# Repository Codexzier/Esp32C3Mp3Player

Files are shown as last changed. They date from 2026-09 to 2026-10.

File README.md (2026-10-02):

# Esp32C3Mp3Player
 A simple MP3 Player with ESP32-C3.

Einfacher MP3 Player auf Basis eines **ESP32-C3 Dev Moduls** (Variante mit I²C auf
GPIO8 = SDA und GPIO9 = SCL, z.B. ESP32-C3 SuperMini). Die MP3s liegen nach Kategorien
sortiert in Ordnern auf einer SD Karte und werden über einen PCM5102 I2S DAC ausgegeben.

## Benötigte Bauteile

| Bauteil | Hinweis |
|---|---|
| ESP32-C3 Dev Modul | Variante SDA = GPIO8, SCL = GPIO9 |
| OLED Display 128x32 | SSD1306, I²C, Adresse 0x3C |
| SD Karten Leser | SPI, FAT32 formatierte SD Karte |
| PCM5102 I2S DAC Modul | "PCM5102 I2S IIS Lossless Digital Audio DAC Decoder" |
| 2 Taster | Schließer, gegen GND |
| Potentiometer 10 kΩ | linear, für die Lautstärke |
| 2 Widerstände 100 kΩ | Spannungsteiler für die Akku Messung |
| LiPo / Li-Ion Akku (1 Zelle) | mit Lade-/Schutzschaltung (z.B. TP4056) |

## Pin Belegung

| GPIO | Funktion | Anschluss am Modul |
|---|---|---|
| GPIO0 | ADC – Lautstärke | Potentiometer Schleifer (Mitte) |
| GPIO1 | ADC – Akku Messung | Mitte Spannungsteiler 100k/100k |
| GPIO2 | I2S Daten | PCM5102 **DIN** |
| GPIO3 | Taster 1 (Play / nächster Titel) | Taster gegen GND |
| GPIO4 | SPI SCK | SD Karte **SCK** |
| GPIO5 | SPI MISO | SD Karte **MISO** |
| GPIO6 | SPI MOSI | SD Karte **MOSI** |
| GPIO7 | SPI CS | SD Karte **CS** |
| GPIO8 | I²C SDA | OLED **SDA** |
| GPIO9 | I²C SCL | OLED **SCL** |
| GPIO10 | I2S Bit Clock | PCM5102 **BCK** |
| GPIO20 | Taster 2 (Stop / nächste Kategorie) | Taster gegen GND |
| GPIO21 | I2S Word Select | PCM5102 **LCK** |

### OLED Display 128x32

| OLED | ESP32-C3 |
|---|---|
| VCC | 3V3 |
| GND | GND |
| SDA | GPIO8 |
| SCL | GPIO9 |

### SD Karten Leser

| SD Modul | ESP32-C3 |
|---|---|
| VCC | 3V3 (bzw. 5V, wenn das Modul einen eigenen Spannungsregler hat) |
| GND | GND |
| SCK | GPIO4 |
| MISO | GPIO5 |
| MOSI | GPIO6 |
| CS | GPIO7 |

### PCM5102 I2S DAC

| PCM5102 | ESP32-C3 / Anschluss |
|---|---|
| VIN | 3V3 (oder 5V) |
| GND | GND |
| BCK | GPIO10 |
| DIN | GPIO2 |
| LCK | GPIO21 |
| SCK | **GND** (der DAC erzeugt den Systemtakt dann selbst) |
| FLT | GND (normaler Filter) |
| DEMP | GND (De-Emphasis aus) |
| XSMT | **3V3** (Soft-Mute aus, sonst bleibt der Ausgang stumm) |
| FMT | GND (I2S Format) |

Bei vielen PCM5102 Modulen sind FLT, DEMP, XSMT und FMT über Lötbrücken (H/L) auf der
Rückseite eingestellt und SCK ist schon mit GND verbunden – dann müssen diese Pins nicht
extra verdrahtet werden. Der Kopfhörer bzw. Verstärker kommt an den Line-Out (3,5 mm Klinke
oder L / G / R).

### Taster

Beide Taster schalten den GPIO gegen GND. Es werden die internen Pull-Up Widerstände
verwendet, externe Widerstände sind nicht nötig.

| Taster | ESP32-C3 | Funktion |
|---|---|---|
| Taster 1 | GPIO3 ↔ GND | Play, bei erneutem Drücken nächster Titel |
| Taster 2 | GPIO20 ↔ GND | Titel anhalten und zur nächsten Kategorie wechseln |

### Potentiometer (Lautstärke)

| Potentiometer | ESP32-C3 |
|---|---|
| Äußerer Pin 1 | GND |
| Schleifer (Mitte) | GPIO0 |
| Äußerer Pin 2 | 3V3 |

### Akku Messung

Der Akku wird über einen Spannungsteiler (2 × 100 kΩ) gemessen, damit am ADC maximal
ca. 2,1 V anliegen:

```
Akku + ──[100k]──┬──[100k]── GND
                 │
               GPIO1
```

Wird keine Akkuspannung erkannt (Betrieb nur über USB), zeigt die Akku Anzeige nur den
Rahmen und es findet keine Abschaltung statt.

### Hinweise zu den Pins

- GPIO20/21 sind beim ESP32-C3 die Pins der UART0 (RX/TX). Da sie hier für Taster 2 und
  den DAC verwendet werden, in der Arduino IDE **"USB CDC On Boot: Enabled"** einstellen,
  damit die serielle Konsole über den nativen USB Anschluss läuft.
- GPIO2, GPIO8 und GPIO9 sind Strapping Pins. Sie werden hier nur als Ausgang (DIN) bzw.
  für I²C genutzt, die Taster liegen bewusst nicht auf diesen Pins.

## Platine (PCB)

Im Ordner [`hardware/`](hardware/) liegt ein KiCad-Projekt (Schaltplan und geroutete Platine,
88 × 52 mm, 2 Lagen). Die Module werden auf beiden Seiten der Platine gesteckt: SuperMini,
OLED, Taster, Poti und Ein/Aus-Schalter auf der Oberseite, SD-Modul, PCM5102, HW-104
(PAM8403) und TP4056 auf der Unterseite. Die Pinbelegung ist dieselbe wie oben. Zusätzlich
sind der Akku-Pfad mit Lademodul, Schalter und Schottky-Diode sowie Kondensatoren gegen
Störgeräusche am Verstärker vorgesehen.

Einige Modulmaße sind geschätzt – vor der Bestellung bitte die Hinweise in der
[Platinen-README](hardware/README.md) beachten.

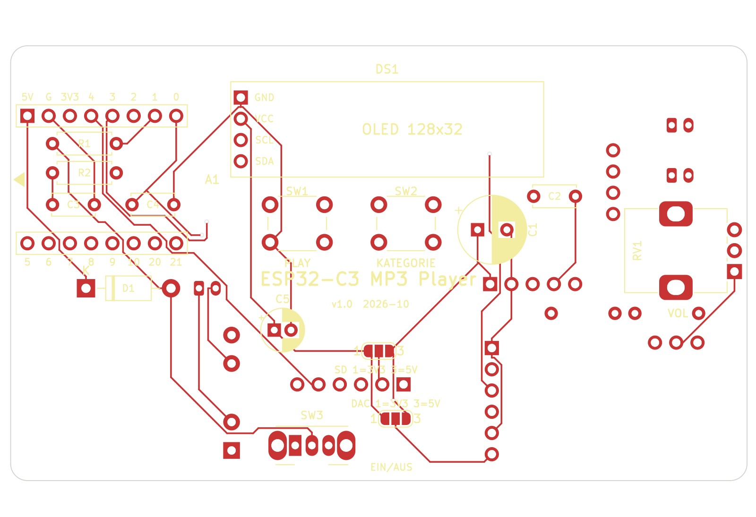
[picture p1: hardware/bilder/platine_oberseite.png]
Platine Oberseite


## SD Karte

Die SD Karte muss FAT32 formatiert sein. Jeder Ordner im Hauptverzeichnis ist eine
Kategorie, die MP3s liegen direkt in diesen Ordnern:

```
/Chillout/Titel 1.mp3
/Dokumentation/...
/Lofi/...
/Work/...
```

Werden auf der SD Karte keine Ordner gefunden, legt der Player die Ordner **Chillout**,
**Work**, **Dokumentation** und **Lofi** an und zeigt den Hinweis, dass noch keine MP3s
gespeichert sind. Standard Kategorie beim Einschalten ist *Chillout*.

## Bedienung / Anzeige

1. **Einschalten:** Schiebetüren Animation, danach der Start Text
   - Zeile 1: `ESP32 MP3 Player`
   - Zeile 2: `Press Play (Anzahl Titel)`
   - Zeile 3: `Kat: <Ordner>`
2. **Taster 1:** Wiedergabe startet
   - Zeile 1: Titel der MP3 (lange Titel laufen als Lauftext durch)
   - Zeile 2: `Anzahl Titel: <Anzahl>`
   - Erneutes Drücken spielt den nächsten Titel, nach dem letzten Titel geht es wieder
     beim ersten los. Ist ein Titel zu Ende, wird automatisch der nächste gespielt.
3. **Taster 2:** Wiedergabe wird angehalten und die nächste Kategorie (Ordner) gewählt.
   Es wird wieder der Start Text mit der neuen Kategorie angezeigt.
4. **Potentiometer:** Lautstärke, angezeigt als 2 Pixel hoher Balken in den unteren beiden
   Pixelzeilen (31 und 32).
5. **Akku:** Wird alle 30 Sekunden und bei jedem Titelwechsel gemessen und rechts als
   Balken angezeigt. Bei 1 % wird die Wiedergabe gestoppt und angezeigt:
   - Zeile 1: `Batteriestand: 1%`
   - Zeile 2: `Bitte Aufladen`
   - Zeile 3: `Abschaltung in 30s` (zählt herunter)

   Bei 0 Sekunden wird das Display abgeschaltet und der ESP32 geht in den Deep Sleep.
   Neustart über Reset bzw. Aus- und wieder Einschalten.

## Software

Arduino IDE mit dem **esp32** Board Paket von Espressif (Version 3.x), Board
**"ESP32C3 Dev Module"**, *USB CDC On Boot: Enabled*.

Benötigte Bibliotheken:

- Adafruit GFX Library
- Adafruit SSD1306
- [arduino-audio-tools](https://github.com/pschatzmann/arduino-audio-tools)
- [arduino-libhelix](https://github.com/pschatzmann/arduino-libhelix) (MP3 Decoder)

Die beiden Audio Bibliotheken sind nicht im Bibliotheksverwalter enthalten und werden als
ZIP von GitHub heruntergeladen und über *Sketch → Bibliothek einbinden → .ZIP-Bibliothek
hinzufügen* installiert.

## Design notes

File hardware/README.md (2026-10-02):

# Platine ESP32-C3 MP3 Player

KiCad-Projekt für eine doppelseitig bestückte Platine (88 × 52 mm, 2 Lagen). Alle Module
sitzen auf der Platine. Der ESP32-C3 SuperMini wird auf Buchsenleisten gesteckt.

> **Wichtig:** Die Maße und Pin-Positionen einiger Module sind geschätzt (siehe
> [Vor der Bestellung prüfen](#vor-der-bestellung-prüfen)). Bitte die Footprints mit den
> eigenen Modulen vergleichen und bei Bedarf in KiCad anpassen, bevor die Platine bestellt wird.

| Oberseite (Bedienseite) | Unterseite (von unten gesehen) |
|---|---|
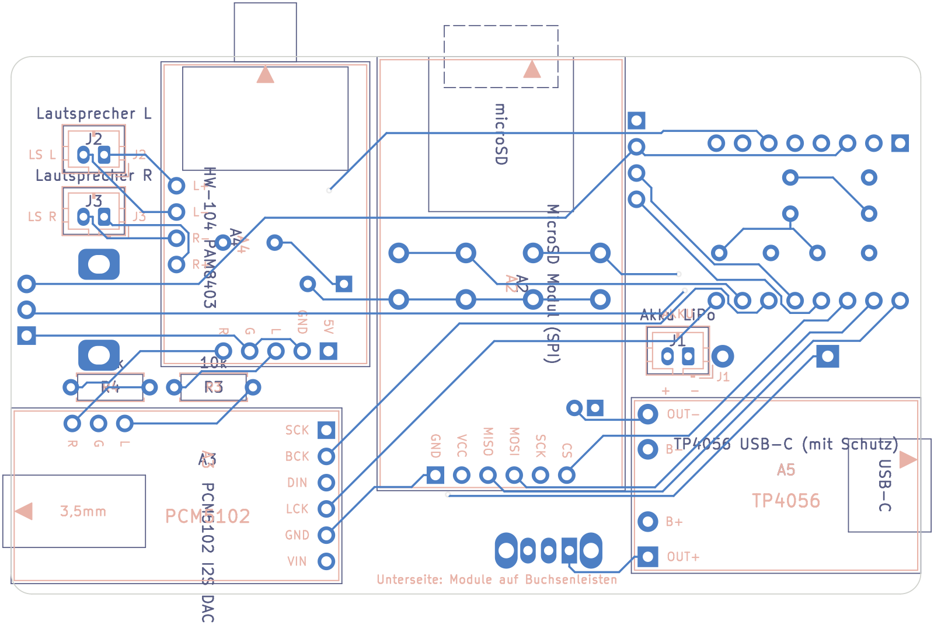
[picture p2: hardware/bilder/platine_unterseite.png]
Unterseite
| Oberseite |  |

Schaltplan: [Esp32C3Mp3Player-Schaltplan.pdf](Esp32C3Mp3Player-Schaltplan.pdf) bzw.
[bilder/schaltplan.png](bilder/schaltplan.png)

## Dateien

| Datei | Inhalt |
|---|---|
| `Esp32C3Mp3Player.kicad_pro` | KiCad-Projekt (Netzklassen: Signale 0,3 mm, Versorgung 0,6 mm) |
| `Esp32C3Mp3Player.kicad_sch` | Schaltplan |
| `Esp32C3Mp3Player.kicad_pcb` | Platine (geroutet, GND-Flächen auf beiden Lagen) |
| `Esp32C3Mp3Player.kicad_sym` | Symbole der Module |
| `Esp32C3Mp3Player.pretty/` | Footprints der Module |
| `fp-lib-table`, `sym-lib-table` | binden die beiden Projekt-Bibliotheken ein |

Erstellt mit KiCad 7.0. Die Dateien lassen sich mit KiCad 8 und 9 öffnen, beim Speichern werden
sie in das neue Format umgewandelt. Standardbauteile (Widerstände, Taster, ...) stammen aus den
KiCad-Standardbibliotheken.

## Aufbau

### Oberseite (Bedienseite)

| Ref | Bauteil | Lage |
|---|---|---|
| A1 | ESP32-C3 SuperMini auf 2 × Buchsenleiste 1×8 | links, USB-C an der linken Kante |
| DS1 | OLED 0,91" 128×32 | oben Mitte |
| SW1, SW2 | Taster 6×6 mm (Play/Next, Kategorie) | unter dem Display |
| RV1 | Poti 10k linear (9 mm, Alps RK09K o.ä.) | rechts |
| SW3 | Schiebeschalter Ein/Aus (C&K OS102011MA1Q, 2 mm Raster) | untere Kante, Hebel zeigt nach außen |
| R1, R2, C3, C4 | Spannungsteiler Akku, Filter-Kondensatoren | unter dem SuperMini |
| D1, C1, C2, C5 | Schottky-Diode, Elkos, 100 nF | freie Flächen |
| JP1, JP2 | Lötbrücken für die Versorgung von SD-Modul und DAC | Mitte unten |

### Unterseite

| Ref | Bauteil | Lage |
|---|---|---|
| A2 | MicroSD-Modul (SPI, 42 × 24 mm) | Mitte, Kartenschlitz an der oberen Kante |
| A3 | PCM5102 DAC | rechts unten, 3,5-mm-Klinke an der rechten Kante |
| A4 | HW-104 (PAM8403) | rechts oben, Poti-Achse an der oberen Kante |
| A5 | TP4056 USB-C Lademodul | links unten, USB-C an der linken Kante |
| J1 | Akku (JST-PH 2 mm) | links |
| J2, J3 | Lautsprecher links/rechts (JST-PH 2 mm) | rechts oben |
| R3, R4 | 10 k Vorwiderstände Audio | zwischen DAC und Verstärker |

Die Module auf der Unterseite werden ebenfalls auf **Buchsenleisten** gesteckt (8,5 mm hoch).
Dadurch ist genug Abstand zu den Lötstellen der Bauteile auf der Oberseite. Nur der **TP4056**
wird mit kurzen Stiftleisten-Pins direkt angelötet; unter ihm liegen deshalb keine Lötstellen.

## Schaltung

Die Pinbelegung des ESP32-C3 ist dieselbe wie in der [README](../README.md) und im Sketch:

| GPIO | Signal | GPIO | Signal |
|---|---|---|---|
| GPIO0 | Poti (Lautstärke) | GPIO6 | SD MOSI |
| GPIO1 | Akku-Messung | GPIO7 | SD CS |
| GPIO2 | I2S DIN → PCM5102 | GPIO8 | I²C SDA (OLED) |
| GPIO3 | Taster Play/Next | GPIO9 | I²C SCL (OLED) |
| GPIO4 | SD SCK | GPIO10 | I2S BCK → PCM5102 |
| GPIO5 | SD MISO | GPIO20 | Taster Kategorie |
| | | GPIO21 | I2S LCK → PCM5102 |

**Stromversorgung:** Akku (J1) → TP4056 (B+/B−) → OUT+ → Schalter SW3 → Schottky-Diode D1 →
5V-Pin des SuperMini. Geladen wird über die USB-C-Buchse des TP4056. Steckt USB am SuperMini,
läuft der Player über USB; D1 verhindert, dass dabei 5 V in den Akku zurückfließen. R1/R2 teilen
die Akkuspannung (hinter dem Schalter) für GPIO1. Ist der Schalter aus, misst die Firmware keinen
Akku und schaltet nicht ab.

**Audio:** PCM5102 L/R → R3/R4 (10 k) → Eingang HW-104 → Lautsprecher an J2/J3 (Brückenausgang:
L+/L− bzw. R+/R−, **nicht** mit GND verbinden). C1 (470 µF) und C2 (100 nF) sitzen direkt an der
Versorgung des Verstärkers, beide Lagen sind GND-Flächen. Das hilft gegen das Störgeräusch.
Ist es zu leise, R3/R4 durch Drahtbrücken ersetzen. SCK des PCM5102 liegt auf GND (interner Takt).

### Lötbrücken JP1 und JP2 (müssen geschlossen werden!)

Ohne Brücke bekommen SD-Modul bzw. DAC keinen Strom. Die mittlere Fläche (2) wird mit einer der
äußeren verbunden:

| Brücke | 1–2 (3,3 V) | 2–3 (5 V) |
|---|---|---|
| JP1 (SD-Modul) | SD-Modul ohne eigenen Spannungsregler | Catalex-Modul mit AMS1117-Regler |
| JP2 (PCM5102) | empfohlen | möglich (Modul hat eigene Regler) |

Hinweis zum Akkubetrieb: Am 5V-Pin liegen dann nur etwa 3,0 – 3,9 V (Akku minus Diode). Ein
SD-Modul mit AMS1117-Regler bekommt daran zu wenig Spannung. Für Akkubetrieb ein SD-Modul ohne
Regler an 3,3 V nehmen (JP1 auf 1–2).

## Stückliste

| Ref | Wert | Bauform / Footprint | Menge |
|---|---|---|---|
| A1 | ESP32-C3 SuperMini | + 2 × Buchsenleiste 1×8, 2,54 mm | 1 |
| DS1 | OLED 0,91" 128×32 I²C | + Buchsenleiste 1×4 | 1 |
| A2 | MicroSD-Modul SPI | + Buchsenleiste 1×6 | 1 |
| A3 | PCM5102 DAC | + Buchsenleisten 1×6 und 1×3 | 1 |
| A4 | HW-104 PAM8403 | + Buchsenleisten 1×5 und 1×4 | 1 |
| A5 | TP4056 USB-C mit Schutzschaltung | 4 einzelne Stiftleisten-Pins | 1 |
| SW1, SW2 | Taster | 6 × 6 mm THT | 2 |
| SW3 | Schiebeschalter 1×UM | C&K OS102011MA1Q (2 mm Raster, gewinkelt) | 1 |
| RV1 | 10 k linear | Alps RK09K stehend (9 mm) | 1 |
| R1, R2 | 100 k | 0207, Raster 7,62 mm | 2 |
| R3, R4 | 10 k | 0207, Raster 7,62 mm | 2 |
| C1 | 470 µF / 10 V | Elko radial 8 mm, Raster 3,5 mm | 1 |
| C5 | 100 µF / 10 V | Elko radial 5 mm, Raster 2 mm | 1 |
| C2, C3, C4 | 100 nF | Keramik, Raster 5 mm | 3 |
| D1 | 1N5817 | DO-41 | 1 |
| J1, J2, J3 | JST-PH 2-polig | B2B-PH-K, stehend | 3 |
| H1–H4 | Befestigungsloch M3 | | 4 |

## Bestückung

1. Lötbrücken JP1 und JP2 setzen (siehe oben).
2. Flache Bauteile auf der Oberseite: R1, R2, C3, C4 (unter dem SuperMini), D1, C2, C5.
3. Taster, Poti, Schiebeschalter, C1.
4. Buchsenleisten für SuperMini und OLED auf der Oberseite.
5. Unterseite: R3, R4, J1–J3, dann die Buchsenleisten für SD-Modul, PCM5102 und HW-104.
6. TP4056 mit kurzen Pins auf der Unterseite anlöten.
7. Module aufstecken.

Die Lötstellen der Buchsenleisten liegen jeweils auf der Gegenseite. Deshalb die Buchsenleisten
löten, bevor die Module aufgesteckt werden.

## Vor der Bestellung prüfen

Einige Datenblätter waren nicht erreichbar. Diese Angaben sind deshalb geschätzt:

| Modul | Annahme | Was prüfen |
|---|---|---|
| ESP32-C3 SuperMini | 22,52 × 18 mm, Reihenabstand 15,24 mm, Pin 1 (5V) 2 mm von der USB-Kante. Von oben, USB links: obere Reihe 5V, GND, 3V3, 4, 3, 2, 1, 0; untere Reihe 5, 6, 7, 8, 9, 10, 20, 21 | Reihenfolge der Pinreihen. Sind die Reihen vertauscht, lässt sich der SuperMini mit der Bauteilseite nach unten aufstecken (USB bleibt links). Besser: Footprint anpassen |
| OLED 0,91" | 38 × 12 mm, Pins GND, VCC, SCL, SDA | Bei manchen Modulen sind VCC und GND vertauscht! |
| MicroSD-Modul | 42 × 24 mm (Catalex-Bauform), Pins GND, VCC, MISO, MOSI, SCK, CS, 4 Löcher M2 | Pinreihenfolge und Lage der Befestigungslöcher |
| PCM5102 | 17 × 32 mm, Leiste SCK, BCK, DIN, LCK, GND, VIN an einer kurzen Seite, L/G/R an der langen Seite, Klinke an der anderen kurzen Seite | Größe und Lage aller Pins |
| HW-104 | 29,5 × 20,2 mm, Poti links; 5V, GND, L, G, R rechts; L+, L−, R−, R+ unten (Raster 2,54 mm) | am ungenauesten geschätzt – alle Pins prüfen |
| TP4056 | 28 × 17 mm, Pads OUT+, B+, B−, OUT− an der Schmalseite gegenüber USB-C | Abstand der Pads |
| Poti, Schalter, JST | Alps RK09K, C&K OS102011MA1Q, JST-PH | passen die eigenen Bauteile? Polarität des Akkusteckers (+ an Pin 1) |

**Footprint anpassen:** In KiCad den Footprint-Editor öffnen, Bibliothek `Esp32C3Mp3Player`,
Pads verschieben, speichern. Danach in der Platine *Werkzeuge → Footprints aus Bibliothek
aktualisieren* ausführen. Betroffene Leiterbahnen neu verlegen und die Flächen mit `B` neu
füllen. Anschließend den DRC laufen lassen.

**Bestellen:** *Datei → Fertigungsdateien → Gerber* (Lagen F/B.Cu, F/B.Mask, F/B.Silkscreen,
Edge.Cuts) und *Bohrdateien*. Die Mindestmaße (Leiterbahn 0,3 mm, Abstand 0,2 mm, Bohrung
0,4 mm) schafft jeder übliche Platinenhersteller.

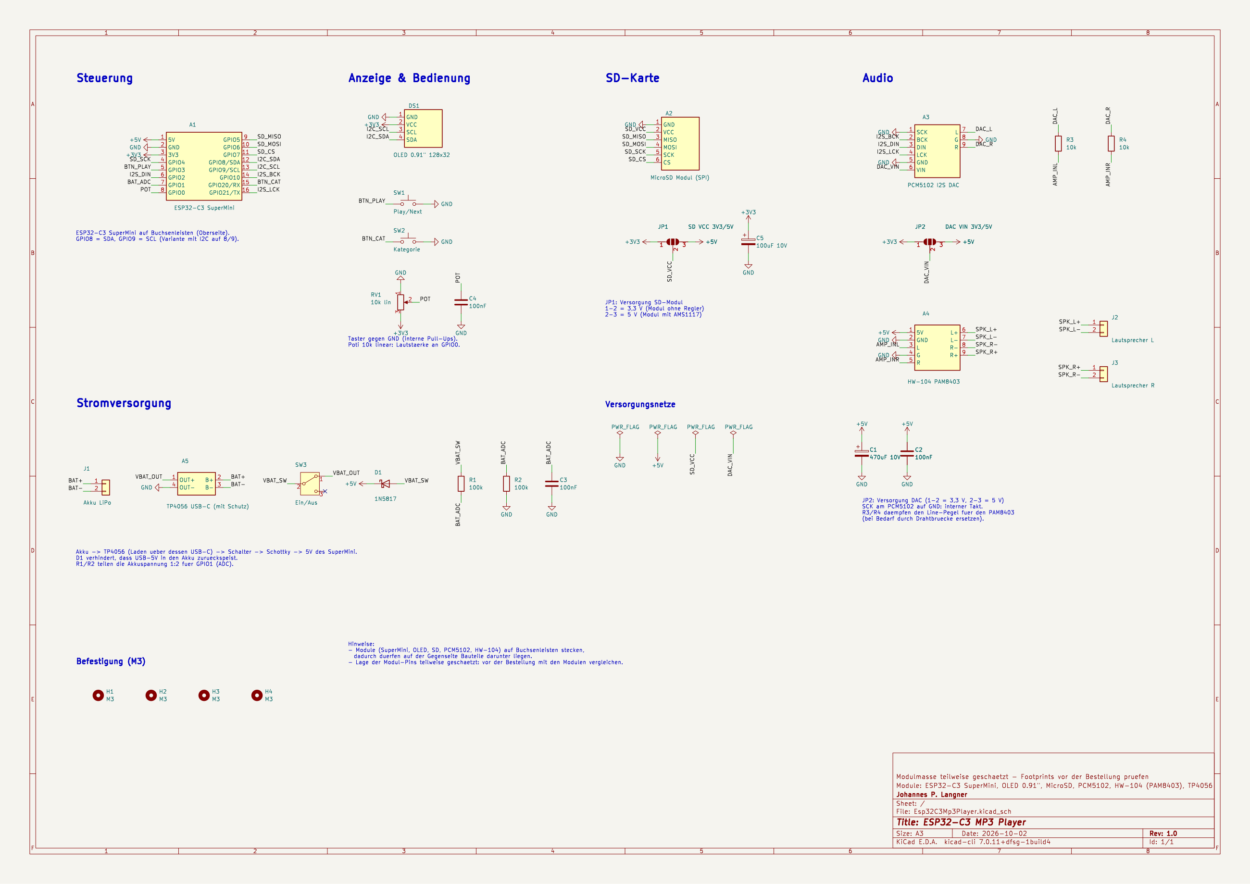
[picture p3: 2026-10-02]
hardware/bilder/schaltplan.png

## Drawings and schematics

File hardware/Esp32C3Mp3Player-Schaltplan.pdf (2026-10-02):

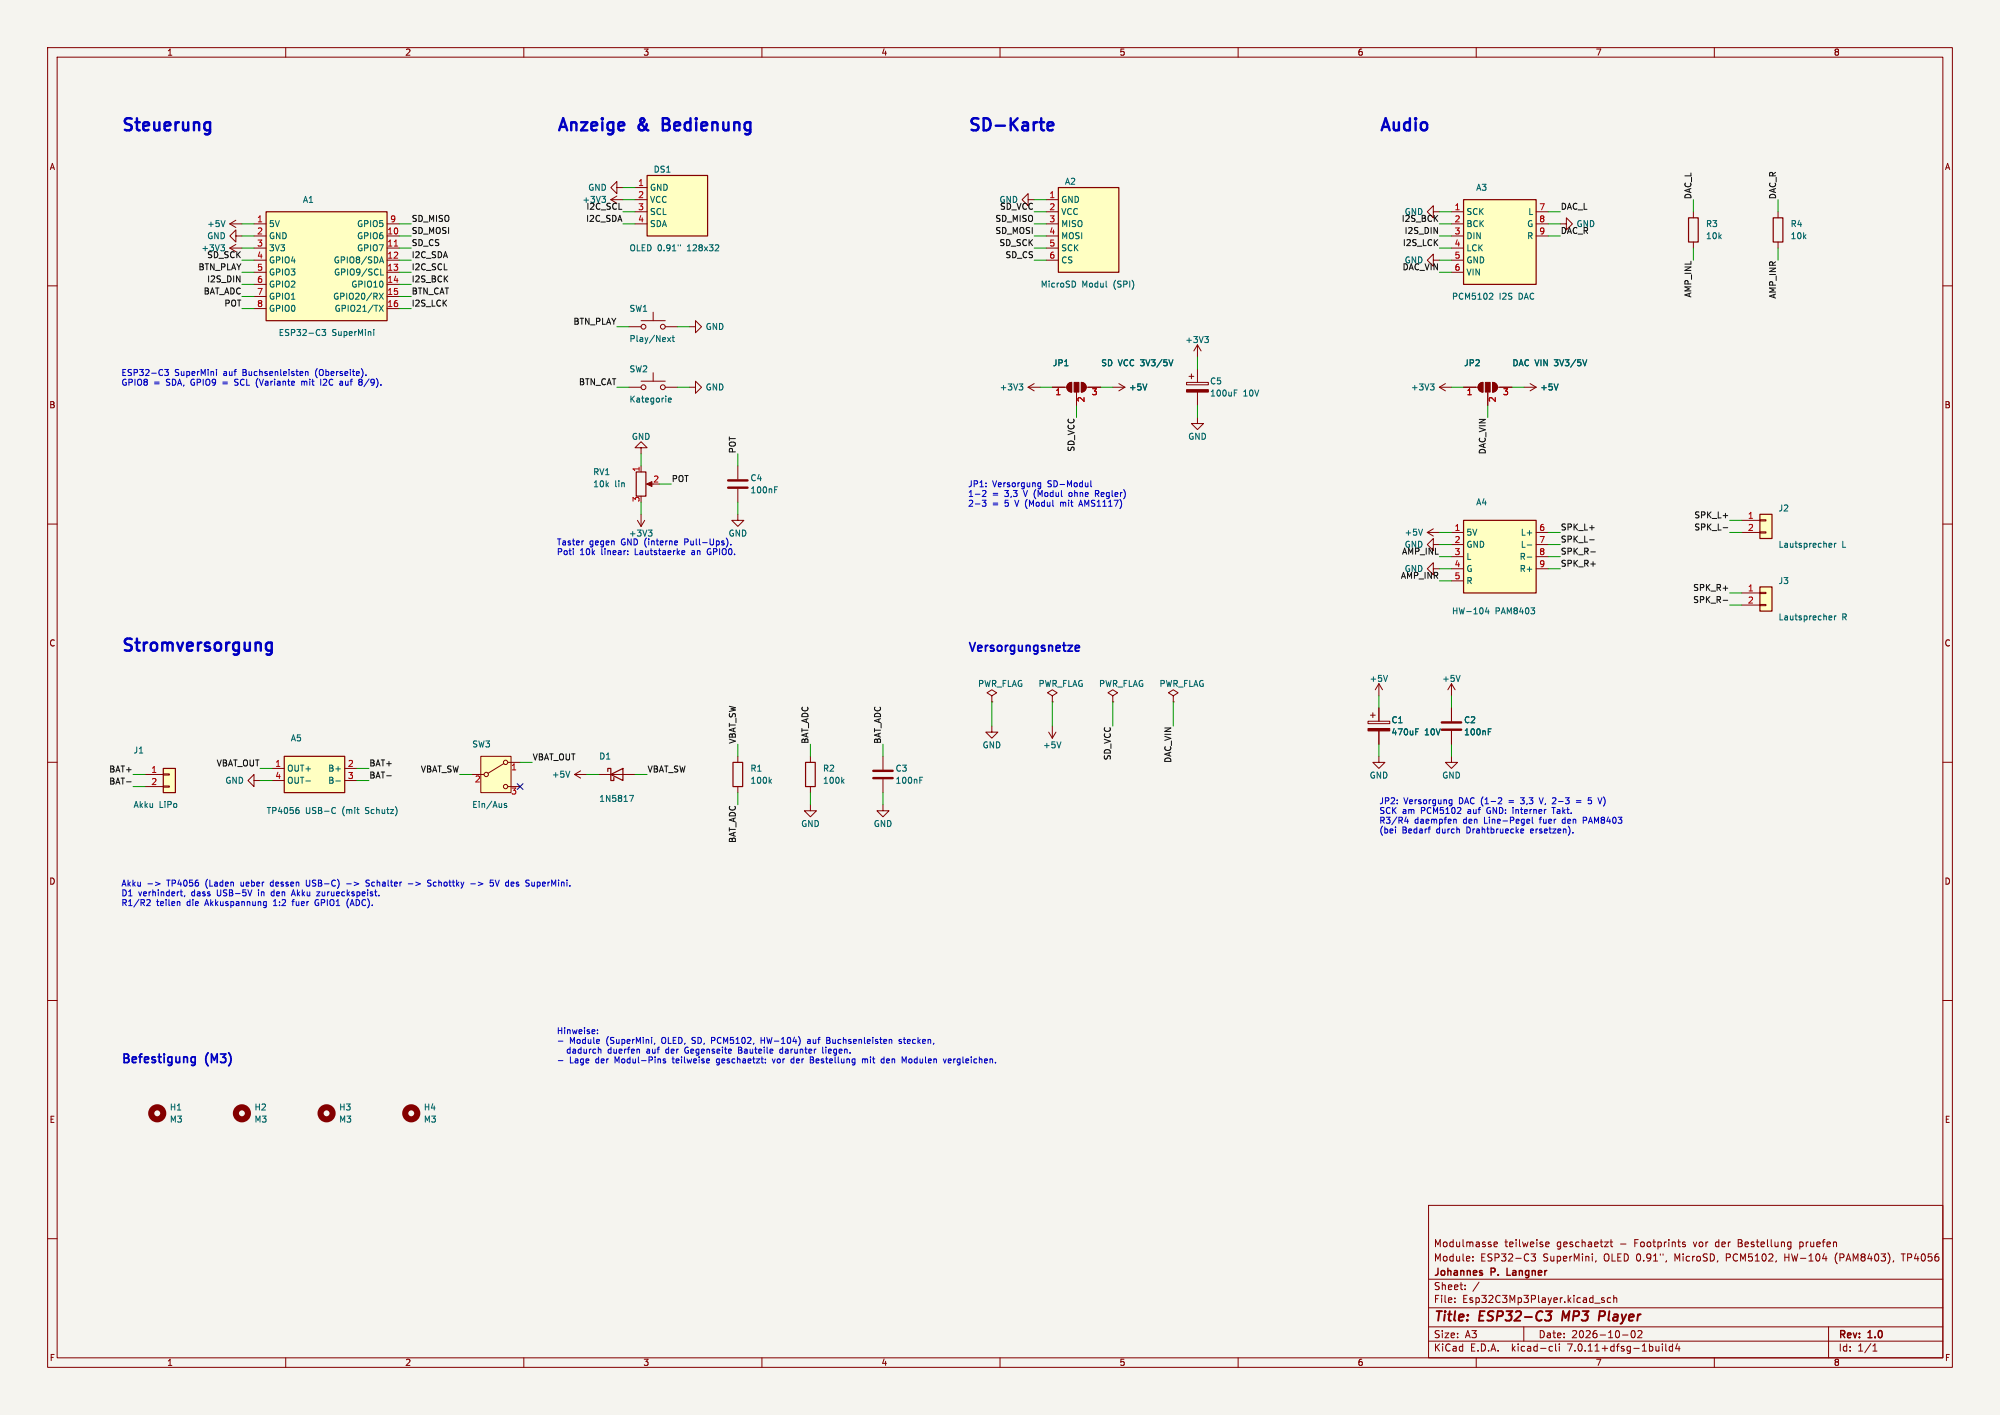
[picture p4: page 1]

GND 1 VCC 2 MISO 3 MOSI 4 SCK 5 CS 6 A2 MicroSD Modul (SPI) D1

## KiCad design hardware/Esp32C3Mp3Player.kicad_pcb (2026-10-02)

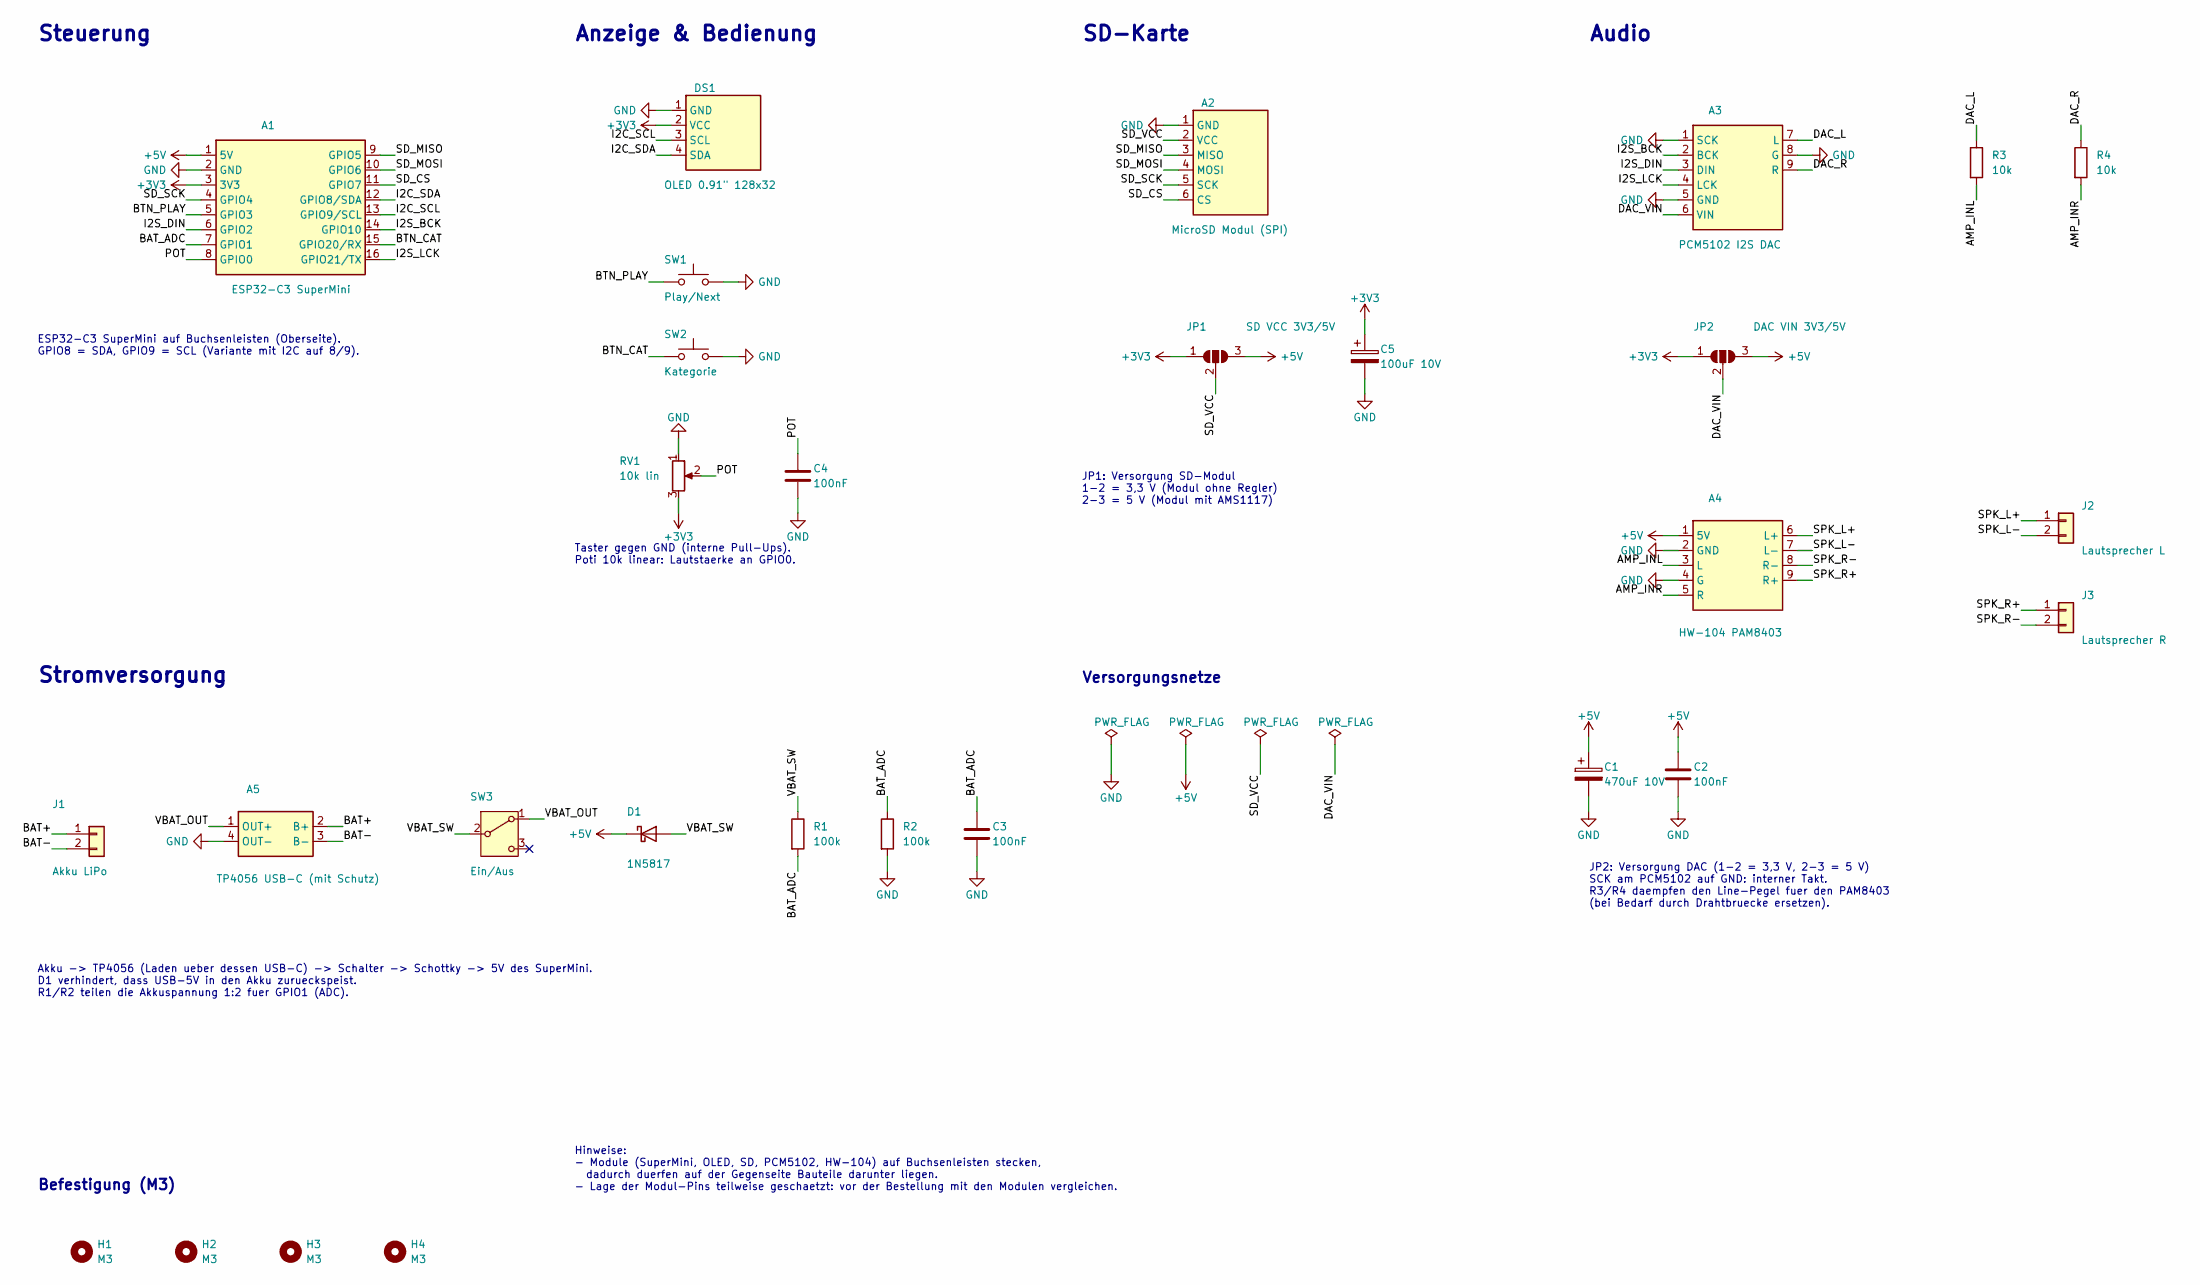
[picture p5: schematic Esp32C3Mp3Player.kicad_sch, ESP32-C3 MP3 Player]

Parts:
A1: ESP32-C3 SuperMini; ESP32-C3_SuperMini_Socket
A2: MicroSD Modul (SPI); SD_Card_Module_SPI_42x24mm
A3: PCM5102 I2S DAC; PCM5102_DAC_Module_17x32mm
A4: HW-104 PAM8403; HW-104_PAM8403_Module
A5: TP4056 USB-C (mit Schutz); TP4056_Module_USB-C_28x17mm
C1: 470uF 10V; CP_Radial_D8.0mm_P3.50mm
C2, C3, C4: 100nF; C_Disc_D5.0mm_W2.5mm_P5.00mm
C5: 100uF 10V; CP_Radial_D5.0mm_P2.00mm
D1: 1N5817; D_DO-41_SOD81_P10.16mm_Horizontal
DS1: OLED 0.91" 128x32; OLED_0.91in_128x32_I2C
H1, H2, H3, H4: M3; MountingHole_3.2mm_M3
J1: Akku LiPo; JST_PH_B2B-PH-K_1x02_P2.00mm_Vertical
J2: Lautsprecher L; JST_PH_B2B-PH-K_1x02_P2.00mm_Vertical
J3: Lautsprecher R; JST_PH_B2B-PH-K_1x02_P2.00mm_Vertical
JP1: SD VCC 3V3/5V; SolderJumper-3_P1.3mm_Open_RoundedPad1.0x1.5mm_NumberLabels
JP2: DAC VIN 3V3/5V; SolderJumper-3_P1.3mm_Open_RoundedPad1.0x1.5mm_NumberLabels
R1, R2: 100k; R_Axial_DIN0207_L6.3mm_D2.5mm_P7.62mm_Horizontal
R3, R4: 10k; R_Axial_DIN0207_L6.3mm_D2.5mm_P7.62mm_Horizontal
RV1: 10k lin; Potentiometer_Alps_RK09K_Single_Vertical
SW1: Play/Next; SW_PUSH_6mm
SW2: Kategorie; SW_PUSH_6mm
SW3: Ein/Aus; SW_Slide_SPDT_Angled_CK_OS102011MA1Q

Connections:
+3V3: A1.3 (3V3), C5.1, DS1.2 (VCC), JP1.1 (A), JP2.1 (A), RV1.3
+5V: A1.1 (5V), A4.1 (5V), C1.1, C2.1, D1.1 (K), JP1.3 (B), JP2.3 (B)
AMP_INL: A4.3 (L), R3.2
AMP_INR: A4.5 (R), R4.2
BAT+: A5.2 (B+), J1.1
BAT-: A5.3 (B-), J1.2
BAT_ADC: A1.7 (GPIO1), C3.1, R1.2, R2.1
BTN_CAT: A1.15 (GPIO20/RX), SW2.1
BTN_PLAY: A1.5 (GPIO3), SW1.1
DAC_L: A3.7 (L), R3.1
DAC_R: A3.9 (R), R4.1
DAC_VIN: A3.6 (VIN), JP2.2 (C)
GND: A1.2 (GND), A2.1 (GND), A3.1 (SCK), A3.5 (GND), A3.8 (G), A4.2 (GND), A4.4 (G), A5.4 (OUT-), C1.2, C2.2, C3.2, C4.2, C5.2, DS1.1 (GND), R2.2, RV1.1, SW1.2, SW2.2
I2C_SCL: A1.13 (GPIO9/SCL), DS1.3 (SCL)
I2C_SDA: A1.12 (GPIO8/SDA), DS1.4 (SDA)
I2S_BCK: A1.14 (GPIO10), A3.2 (BCK)
I2S_DIN: A1.6 (GPIO2), A3.3 (DIN)
I2S_LCK: A1.16 (GPIO21/TX), A3.4 (LCK)
POT: A1.8 (GPIO0), C4.1, RV1.2
SD_CS: A1.11 (GPIO7), A2.6 (CS)
SD_MISO: A1.9 (GPIO5), A2.3 (MISO)
SD_MOSI: A1.10 (GPIO6), A2.4 (MOSI)
SD_SCK: A1.4 (GPIO4), A2.5 (SCK)
SD_VCC: A2.2 (VCC), JP1.2 (C)
SPK_L+: A4.6 (L+), J2.1
SPK_L-: A4.7 (L-), J2.2
SPK_R+: A4.9 (R+), J3.1
SPK_R-: A4.8 (R-), J3.2
VBAT_OUT: A5.1 (OUT+), SW3.1 (A)
VBAT_SW: D1.2 (A), R1.1, SW3.2 (B)

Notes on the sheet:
Steuerung
ESP32-C3 SuperMini auf Buchsenleisten (Oberseite). GPIO8 = SDA, GPIO9 = SCL (Variante mit I2C auf 8/9).
Anzeige & Bedienung
Taster gegen GND (interne Pull-Ups). Poti 10k linear: Lautstaerke an GPIO0.
SD-Karte
JP1: Versorgung SD-Modul 1-2 = 3,3 V (Modul ohne Regler) 2-3 = 5 V (Modul mit AMS1117)
Audio
JP2: Versorgung DAC (1-2 = 3,3 V, 2-3 = 5 V) SCK am PCM5102 auf GND: interner Takt. R3/R4 daempfen den Line-Pegel fuer den PAM8403 (bei Bedarf durch Drahtbruecke ersetzen).
Stromversorgung
Akku -> TP4056 (Laden ueber dessen USB-C) -> Schalter -> Schottky -> 5V des SuperMini. D1 verhindert, dass USB-5V in den Akku zurueckspeist. R1/R2 teilen die Akkuspannung 1:2 fuer GPIO1 (ADC).
Versorgungsnetze
Befestigung (M3)
Hinweise: - Module (SuperMini, OLED, SD, PCM5102, HW-104) auf Buchsenleisten stecken, dadurch duerfen auf der Gegenseite Bauteile darunter liegen. - Lage der Modul-Pins teilweise geschaetzt: vor der Bestellung mit den Modulen vergleichen.

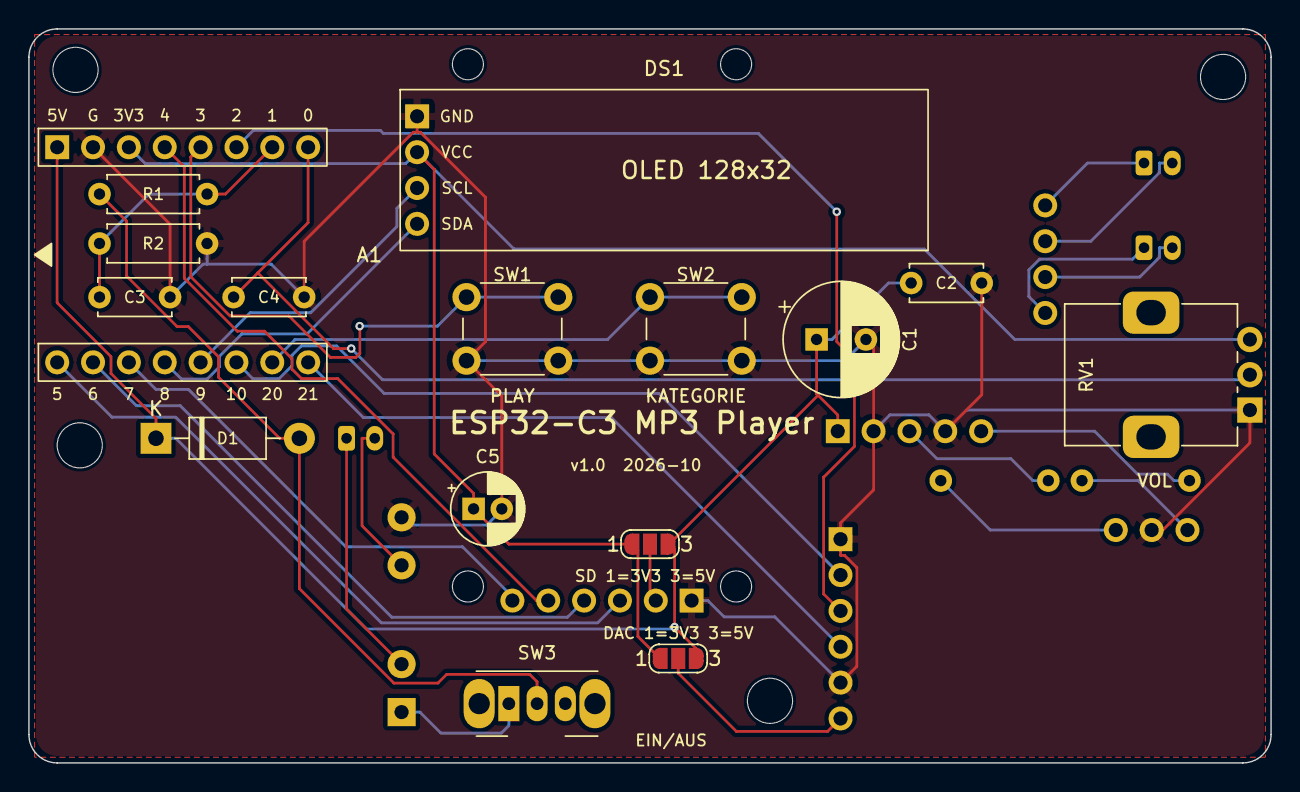
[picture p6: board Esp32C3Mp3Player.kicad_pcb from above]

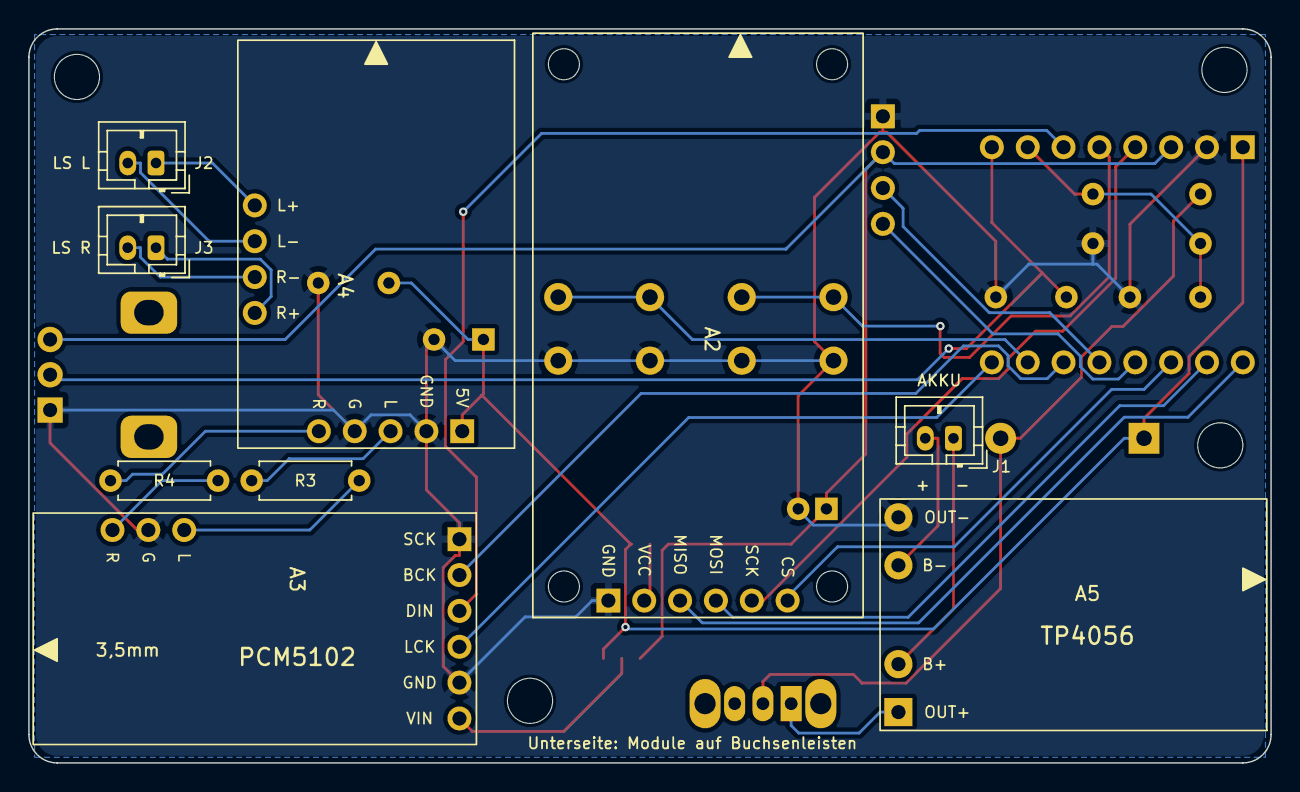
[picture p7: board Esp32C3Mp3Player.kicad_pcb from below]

Board: 2 copper layers, 88.0 x 52.0 mm, 29 parts (9 on the bottom side), 30 nets.

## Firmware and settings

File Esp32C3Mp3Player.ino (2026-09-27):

// ========================================================================================
//      Meine Welt in meinem Kopf
// ========================================================================================
// Projekt:       ESP32 MP3 Player
// Author:        Johannes P. Langner
// Controller:    ESP32-C3 DEV Module (Variante mit I2C: SDA = GPIO8, SCL = GPIO9)
// Description:   Einfacher MP3 Player
//                In den Ordner sind Kategorisch die MP3 nach Musik richtung angelegt.
//                - Chillout
//                - Work
//                - Dokumentation
//                - Lofi
//                Für den Aufbau werden weitere Module benötigt:
//                - PCM5102 I2S IIS (Lossless Digital Audio DAC Decoder)
//                - OLED Display 128x32 (SSD1306, I2C)
//                - SD Karten Leser (SPI)
//                - 2 Taster, 1 Potentiometer (10k), Spannungsteiler für den Akku
//                Die komplette Verdrahtung steht in der README.md
//
// Bibliotheken:  - Adafruit GFX Library
//                - Adafruit SSD1306
//                - arduino-audio-tools  (https://github.com/pschatzmann/arduino-audio-tools)
//                - arduino-libhelix     (https://github.com/pschatzmann/arduino-libhelix)
// Stand:         27.09.2026
// ========================================================================================

#include <Wire.h>
#include <SPI.h>
#include <SD.h>
#include <Adafruit_GFX.h>
#include <Adafruit_SSD1306.h>
#include <vector>
#include <algorithm>
#include "AudioTools.h"
#include "AudioTools/AudioCodecs/CodecMP3Helix.h"
#include "esp_sleep.h"

// ========================================================================================
// Pin Belegung
// ========================================================================================
// I2C (OLED Display)
#define PIN_I2C_SDA        8
#define PIN_I2C_SCL        9

// SPI (SD Karten Leser)
#define PIN_SD_SCK         4
#define PIN_SD_MISO        5
#define PIN_SD_MOSI        6
#define PIN_SD_CS          7

// I2S (PCM5102 DAC)
#define PIN_DAC_BCK       10  // PCM5102: BCK
#define PIN_DAC_LCK       21  // PCM5102: LCK (Word Select)
#define PIN_DAC_DIN        2  // PCM5102: DIN

// Taster (gegen GND, interner Pull-Up)
#define PIN_BUTTON_PLAY    3  // Taster 1: Play / nächster Titel
#define PIN_BUTTON_CAT    20  // Taster 2: Stop / nächste Kategorie

// Analog Eingänge (ADC1)
#define PIN_POTI           0  // Schleifer des Potentiometers (Lautstärke)
#define PIN_BATTERY        1  // Akku über Spannungsteiler 100k / 100k

// ========================================================================================
// Einstellungen
// ========================================================================================
#define SCREEN_WIDTH 128 // OLED Display Breite, in Pixel
#define SCREEN_HEIGHT 32 // OLED Display Höhe, in Pixel
#define OLED_RESET     -1 // Reset-Pin (wird nicht benötigt, daher -1)
#define OLED_ADDRESS 0x3C // Adresse des Displays ist meist 0x3C oder 0x3D

#define SD_SPI_FREQUENCY      10000000UL  // bei Lesefehlern auf 4000000 reduzieren
#define DEFAULT_CATEGORY      "Chillout"

#define MAX_TEXT_CHARS        20     // Zeichen pro Zeile links neben der Akku Anzeige
#define VOLUME_BAR_MAX_WIDTH  118    // Lautstärke Balken endet vor der Akku Anzeige
#define VOLUME_BAR_Y          30     // Pixel Zeile 31 und 32 (0-basiert 30 und 31)

#define BUTTON_DEBOUNCE_MS    30
#define POTI_INTERVAL_MS      50
#define BATTERY_INTERVAL_MS   30000UL  // Akku alle 30 Sekunden messen (zusätzlich bei Titelwechsel)
#define SCROLL_INTERVAL_MS    350
#define SCROLL_PAUSE_MS       1500
#define SHUTDOWN_SECONDS      30

#define BATTERY_DIVIDER       2.0f   // Spannungsteiler 100k / 100k
#define BATTERY_MIN_VALID_MV  2500   // darunter ist kein Akku angeschlossen (z.B. nur USB)
#define BATTERY_SHUTDOWN_PCT  1      // bei 1% wird die Abschaltung eingeleitet

// Objekt für das Display erstellen
Adafruit_SSD1306 display(SCREEN_WIDTH, SCREEN_HEIGHT, &Wire, OLED_RESET);

// ========================================================================================
// Audio
// ========================================================================================
I2SStream i2s;                                   // Ausgabe zum PCM5102
VolumeStream volume(i2s);                        // Lautstärke Regelung
MP3DecoderHelix mp3;                             // MP3 Decoder
EncodedAudioStream decoder(&volume, &mp3);       // MP3 -> PCM -> Lautstärke -> I2S
StreamCopy copier;                               // Kopiert die Datei in den Decoder
File audioFile;

// ========================================================================================
// Zustand
// ========================================================================================
enum class PlayerState {
  Idle,        // Start Text "Press Play"
  Playing,     // Titel wird abgespielt
  NoMp3,       // Keine Ordner / MP3s auf der SD Karte
  SdError,     // SD Karte nicht lesbar
  LowBattery,  // Akku leer, Abschaltung läuft
  Off          // Display aus
};

PlayerState mState = PlayerState::Idle;

std::vector<String> mCategories;   // Ordner auf der SD Karte
std::vector<String> mTitles;       // MP3 Dateien im aktuellen Ordner
int mCategoryIndex = 0;
int mTitleIndex = 0;

int mVolumePercent = -1;           // 0..100, -1 = noch nicht gelesen
int mBatteryPercent = -1;          // 0..100, -1 = kein Akku gemessen
uint32_t mLastBatteryMs = 0;
uint32_t mLastPotiMs = 0;

bool mRedraw = true;
uint32_t mScrollLastMs = 0;
int mScrollOffset = 0;

uint32_t mShutdownStartMs = 0;
int mShutdownSecondsLeft = SHUTDOWN_SECONDS;

String mHintText = "";             // kurzer Hinweis in Zeile 2 (z.B. "Keine Titel!")
uint32_t mHintUntilMs = 0;

// ========================================================================================
// Taster mit Entprellung
// ========================================================================================
struct Button {
  uint8_t pin;
  bool stableState;      // true = gedrückt
  bool lastRead;
  uint32_t lastChangeMs;

  void begin(uint8_t p) {
    pin = p;
    pinMode(pin, INPUT_PULLUP);
    stableState = false;
    lastRead = false;
    lastChangeMs = 0;
  }

  // liefert true, genau einmal pro Tastendruck
  bool pressed() {
    bool reading = digitalRead(pin) == LOW;
    uint32_t now = millis();
    if (reading != lastRead) {
      lastRead = reading;
      lastChangeMs = now;
    }
    if ((now - lastChangeMs) > BUTTON_DEBOUNCE_MS && reading != stableState) {
      stableState = reading;
      return stableState;
    }
    return false;
  }
};

Button mButtonPlay;
Button mButtonCategory;

// ========================================================================================
// Hilfsfunktionen Text
// ========================================================================================

// Der Standard Font kennt kein UTF-8, daher Umlaute ersetzen.
String toDisplayText(const String &text) {
  String result;
  result.reserve(text.length() + 4);
  for (size_t i = 0; i < text.length(); i++) {
    uint8_t c = (uint8_t)text[i];
    if (c == 0xC3 && i + 1 < text.length()) {
      uint8_t n = (uint8_t)text[++i];
      switch (n) {
        case 0xA4: result += "ae"; break;
        case 0xB6: result += "oe"; break;
        case 0xBC: result += "ue"; break;
        case 0x84: result += "Ae"; break;
        case 0x96: result += "Oe"; break;
        case 0x9C: result += "Ue"; break;
        case 0x9F: result += "ss"; break;
        default:   result += '?'; break;
      }
    }
    else if (c >= 0x80) {
      // sonstige Sonderzeichen überspringen
      if (c >= 0xC0) result += '?';
    }
    else {
      result += (char)c;
    }
  }
  return result;
}

String titleName(const String &fileName) {
  String name = fileName;
  int dot = name.lastIndexOf('.');
  if (dot > 0) {
    name = name.substring(0, dot);
  }
  return toDisplayText(name);
}

bool isMp3File(const String &name) {
  if (name.startsWith(".")) return false;  // z.B. "._titel.mp3" von macOS
  String lower = name;
  lower.toLowerCase();
  return lower.endsWith(".mp3");
}

bool lessIgnoreCase(const String &a, const String &b) {
  return strcasecmp(a.c_str(), b.c_str()) < 0;
}

// ========================================================================================
// SD Karte
// ========================================================================================

void loadCategories() {
  mCategories.clear();
  File root = SD.open("/");
  if (!root) return;

  File entry = root.openNextFile();
  while (entry) {
    if (entry.isDirectory()) {
      String name = entry.name();
      if (!name.startsWith(".") && name != "System Volume Information") {
        mCategories.push_back(name);
      }
    }
    entry.close();
    entry = root.openNextFile();
  }
  root.close();

  std::sort(mCategories.begin(), mCategories.end(), lessIgnoreCase);
}

void createDefaultCategories() {
  const char *defaults[] = { "Chillout", "Work", "Dokumentation", "Lofi" };
  for (const char *name : defaults) {
    String path = String("/") + name;
    SD.mkdir(path);
  }
  loadCategories();
}

void loadTitles() {
  mTitles.clear();
  mTitleIndex = 0;
  if (mCategories.empty()) return;

  File dir = SD.open("/" + mCategories[mCategoryIndex]);
  if (!dir) return;

  File entry = dir.openNextFile();
  while (entry) {
    if (!entry.isDirectory()) {
      String name = entry.name();
      if (isMp3File(name)) {
        mTitles.push_back(name);
      }
    }
    entry.close();
    entry = dir.openNextFile();
  }
  dir.close();

  std::sort(mTitles.begin(), mTitles.end(), lessIgnoreCase);
}

// Liest die SD Karte ein und legt ggf. die Standard Ordner an.
void initLibrary() {
  loadCategories();

  if (mCategories.empty()) {
    createDefaultCategories();
    mState = PlayerState::NoMp3;
    return;
  }

  mCategoryIndex = 0;
  for (size_t i = 0; i < mCategories.size(); i++) {
    if (mCategories[i].equalsIgnoreCase(DEFAULT_CATEGORY)) {
      mCategoryIndex = i;
      break;
    }
  }
  loadTitles();
  mState = PlayerState::Idle;
}

// ========================================================================================
// Audio Steuerung
// ========================================================================================

void setupAudio() {
  auto cfg = i2s.defaultConfig(TX_MODE);
  cfg.pin_bck = PIN_DAC_BCK;
  cfg.pin_ws = PIN_DAC_LCK;
  cfg.pin_data = PIN_DAC_DIN;
  cfg.pin_mck = -1;              // PCM5102 erzeugt den Systemtakt selbst (SCK auf GND)
  cfg.sample_rate = 44100;
  cfg.channels = 2;
  cfg.bits_per_sample = 16;
  cfg.buffer_count = 12;         // etwas mehr Puffer, damit das Display Update nicht stört
  cfg.buffer_size = 512;
  i2s.begin(cfg);

  volume.begin(cfg);
  volume.setVolume(0.0f);
}

void stopPlayback() {
  copier.end();
  decoder.end();
  if (audioFile) {
    audioFile.close();
  }
}

// Öffnet den Titel mit dem Index; bei Fehlern wird der nächste Titel versucht.
bool startTrack(int index) {
  stopPlayback();
  if (mTitles.empty()) return false;

  for (size_t attempt = 0; attempt < mTitles.size(); attempt++) {
    mTitleIndex = (index + attempt) % mTitles.size();
    String path = "/" + mCategories[mCategoryIndex] + "/" + mTitles[mTitleIndex];
    audioFile = SD.open(path);
    if (audioFile) {
      decoder.begin();
      copier.begin(decoder, audioFile);
      mScrollOffset = 0;
      mScrollLastMs = millis();
      mRedraw = true;
      return true;
    }
  }
  return false;
}

void measureBattery();

void playNextTrack() {
  int next = mTitleIndex + 1;
  if (next >= (int)mTitles.size()) {
    next = 0;  // nach dem letzten Titel wieder von vorne
  }
  measureBattery();  // Akku zusätzlich bei jedem Titelwechsel prüfen
  if (mState != PlayerState::Playing) return;  // Akku leer
  if (!startTrack(next)) {
    mState = PlayerState::Idle;
    mRedraw = true;
  }
}

void processAudio() {
  copier.copy();
  if (!audioFile || audioFile.available() == 0) {
    // Titel zu Ende -> nächster Titel
    playNextTrack();
  }
}

// ========================================================================================
// Eingaben
// ========================================================================================

void showHint(const String &text, uint32_t durationMs) {
  mHintText = text;
  mHintUntilMs = millis() + durationMs;
  mRedraw = true;
}

void handleButtons() {
  bool playPressed = mButtonPlay.pressed();
  bool categoryPressed = mButtonCategory.pressed();

  if (mState == PlayerState::LowBattery || mState == PlayerState::Off
      || mState == PlayerState::NoMp3 || mState == PlayerState::SdError) {
    return;
  }

  if (playPressed) {
    if (mState == PlayerState::Idle) {
      if (mTitles.empty()) {
        showHint("Keine Titel!", 2000);
      }
      else if (startTrack(mTitleIndex)) {
        mState = PlayerState::Playing;
        measureBattery();
      }
      else {
        showHint("Lesefehler!", 2000);
      }
    }
    else if (mState == PlayerState::Playing) {
      playNextTrack();
    }
  }

  if (categoryPressed && !mCategories.empty()) {
    stopPlayback();
    mCategoryIndex = (mCategoryIndex + 1) % mCategories.size();
    loadTitles();
    mState = PlayerState::Idle;
    mHintUntilMs = 0;
    mRedraw = true;
  }
}

int readAnalogAverage(uint8_t pin, int samples) {
  uint32_t sum = 0;
  for (int i = 0; i < samples; i++) {
    sum += analogRead(pin);
  }
  return sum / samples;
}

void updateVolume(uint32_t now) {
  if (now - mLastPotiMs < POTI_INTERVAL_MS) return;
  mLastPotiMs = now;

  int raw = readAnalogAverage(PIN_POTI, 8);         // 0..4095
  int percent = (raw * 100L + 2047) / 4095;

  // Hysterese gegen Flackern, Endwerte werden immer übernommen
  if (mVolumePercent < 0 || abs(percent - mVolumePercent) >= 2
      || (percent == 0 && mVolumePercent != 0)
      || (percent == 100 && mVolumePercent != 100)) {
    mVolumePercent = percent;
    // quadratische Kurve, damit die Lautstärke gleichmäßiger empfunden wird
    float v = mVolumePercent / 100.0f;
    volume.setVolume(v * v);
    mRedraw = true;
  }
}

// ========================================================================================
// Akku
// ========================================================================================

// Entladekurve LiPo / Li-Ion (1 Zelle), Spannung in mV -> Prozent
int batteryPercentFromMillivolts(int mv) {
  static const int table[][2] = {
    { 4200, 100 }, { 4100, 90 }, { 4000, 80 }, { 3900, 65 }, { 3800, 50 },
    { 3750, 40 },  { 3700, 30 }, { 3650, 20 }, { 3600, 12 }, { 3500, 6 },
    { 3400, 3 },   { 3300, 1 },  { 3200, 0 }
  };
  const int count = sizeof(table) / sizeof(table[0]);
  if (mv >= table[0][0]) return 100;
  if (mv <= table[count - 1][0]) return 0;
  for (int i = 1; i < count; i++) {
    if (mv >= table[i][0]) {
      int mvHigh = table[i - 1][0], pctHigh = table[i - 1][1];
      int mvLow = table[i][0], pctLow = table[i][1];
      return pctLow + (long)(mv - mvLow) * (pctHigh - pctLow) / (mvHigh - mvLow);
    }
  }
  return 0;
}

int readBatteryMillivolts() {
  uint32_t sum = 0;
  const int samples = 16;
  for (int i = 0; i < samples; i++) {
    sum += analogReadMilliVolts(PIN_BATTERY);
  }
  return (int)((sum / samples) * BATTERY_DIVIDER);
}

void startShutdown() {
  stopPlayback();
  mState = PlayerState::LowBattery;
  mShutdownStartMs = millis();
  mShutdownSecondsLeft = SHUTDOWN_SECONDS;
  mRedraw = true;
}

void measureBattery() {
  mLastBatteryMs = millis();
  int mv = readBatteryMillivolts();

  int percent;
  if (mv < BATTERY_MIN_VALID_MV) {
    percent = -1;  // kein Akku angeschlossen (Betrieb über USB)
  }
  else {
    percent = batteryPercentFromMillivolts(mv);
    if (percent <= BATTERY_SHUTDOWN_PCT) {
      // zur Sicherheit nochmal messen, bevor abgeschaltet wird
      int mv2 = readBatteryMillivolts();
      int percent2 = batteryPercentFromMillivolts(mv2);
      if (mv2 >= BATTERY_MIN_VALID_MV && percent2 <= BATTERY_SHUTDOWN_PCT) {
        percent = percent2;
      }
      else {
        percent = BATTERY_SHUTDOWN_PCT + 1;
      }
    }
  }

  if (percent != mBatteryPercent) {
    mBatteryPercent = percent;
    mRedraw = true;
  }

  if (mBatteryPercent >= 0 && mBatteryPercent <= BATTERY_SHUTDOWN_PCT
      && mState != PlayerState::LowBattery && mState != PlayerState::Off) {
    startShutdown();
  }
}

void updateBattery(uint32_t now) {
  if (mState == PlayerState::LowBattery || mState == PlayerState::Off) return;
  if (now - mLastBatteryMs >= BATTERY_INTERVAL_MS) {
    measureBattery();
  }
}

void powerOff() {
  mState = PlayerState::Off;
  display.clearDisplay();
  display.display();
  display.ssd1306_command(SSD1306_DISPLAYOFF);
  i2s.end();
  // Deep Sleep ohne Weckquelle: Neustart nur über Reset oder Aus-/Einschalten
  esp_deep_sleep_start();
}

void updateShutdown(uint32_t now) {
  if (mState != PlayerState::LowBattery) return;
  int left = SHUTDOWN_SECONDS - (int)((now - mShutdownStartMs) / 1000);
  if (left < 0) left = 0;
  if (left != mShutdownSecondsLeft) {
    mShutdownSecondsLeft = left;
    mRedraw = true;
  }
  if (left == 0) {
    powerOff();
  }
}

// ========================================================================================
// Display
// ========================================================================================

void drawBattery() {
  // Bereich rechts neben dem Text frei machen (lange Texte werden hier abgeschnitten)
  display.fillRect(119, 0, 9, SCREEN_HEIGHT, BLACK);
  display.drawRect(120, 0, 8, 32, WHITE);
  if (mBatteryPercent < 0) {
    return;  // kein Akku -> nur der Rahmen
  }

  // mAccuState: 1 für leer, 26 für Voll
  int mAccuState = 1 + (mBatteryPercent * 25 + 50) / 100;
  for (int i = 3; i < 29; i++) {
    if (i < 26 - mAccuState) {
      display.drawFastHLine(122, i, 4, BLACK);
    }
    else {
      display.drawFastHLine(122, i, 4, WHITE);
    }
  }
}

void drawVolumeBar() {
  if (mVolumePercent < 0) return;
  int width = (mVolumePercent * VOLUME_BAR_MAX_WIDTH + 50) / 100;
  if (width > 0) {
    display.fillRect(0, VOLUME_BAR_Y, width, 2, WHITE);
  }
}

void drawTextLine(int row, const String &text) {
  display.setCursor(0, row * 10);
  display.print(text);
}

// Titel, die zu lang für das Display sind, laufen als Lauftext durch
String scrollingText(const String &text) {
  if ((int)text.length() <= MAX_TEXT_CHARS) return text;
  String loop = text + "   " + text;
  int start = mScrollOffset % (text.length() + 3);
  return loop.substring(start, start + MAX_TEXT_CHARS);
}

void updateScroll(uint32_t now) {
  if (mState != PlayerState::Playing || mTitles.empty()) return;
  String title = titleName(mTitles[mTitleIndex]);
  if ((int)title.length() <= MAX_TEXT_CHARS) return;

  uint32_t wait = (mScrollOffset % (title.length() + 3) == 0) ? SCROLL_PAUSE_MS : SCROLL_INTERVAL_MS;
  if (now - mScrollLastMs >= wait) {
    mScrollLastMs = now;
    mScrollOffset++;
    mRedraw = true;
  }
}

String categoryLine() {
  if (mCategories.empty()) return "Kat: -";
  return "Kat: " + toDisplayText(mCategories[mCategoryIndex]);
}

// Zeichnet den aktuellen Inhalt in den Puffer (ohne display())
void renderScreen() {
  display.clearDisplay();
  display.setTextSize(1);
  display.setTextColor(WHITE);
  display.setTextWrap(false);

  bool hintActive = mHintUntilMs != 0 && (int32_t)(millis() - mHintUntilMs) < 0;

  switch (mState) {
    case PlayerState::Idle: {
      drawTextLine(0, "ESP32 MP3 Player");
      if (hintActive) {
        drawTextLine(1, mHintText);
      }
      else {
        drawTextLine(1, "Press Play (" + String(mTitles.size()) + ")");
      }
      drawTextLine(2, categoryLine());
      drawVolumeBar();
      drawBattery();
      break;
    }

    case PlayerState::Playing: {
      drawTextLine(0, scrollingText(titleName(mTitles[mTitleIndex])));
      drawTextLine(1, "Anzahl Titel: " + String(mTitles.size()));
      drawTextLine(2, categoryLine());
      drawVolumeBar();
      drawBattery();
      break;
    }

    case PlayerState::NoMp3: {
      drawTextLine(0, "Noch keine MP3s");
      drawTextLine(1, "auf der SD Karte");
      drawTextLine(2, "gespeichert!");
      break;
    }

    case PlayerState::SdError: {
      drawTextLine(0, "SD Karte Fehler!");
      drawTextLine(1, "Karte einlegen");
      drawTextLine(2, "und neu starten");
      break;
    }

    case PlayerState::LowBattery: {
      drawTextLine(0, "Batteriestand: " + String(mBatteryPercent < 0 ? 0 : mBatteryPercent) + "%");
      drawTextLine(1, "Bitte Aufladen");
      drawTextLine(2, "Abschaltung in " + String(mShutdownSecondsLeft) + "s");
      drawBattery();
      break;
    }

    case PlayerState::Off:
      break;
  }
}

void updateDisplay(uint32_t now) {
  if (mState == PlayerState::Off) return;

  if (mHintUntilMs != 0 && (int32_t)(now - mHintUntilMs) >= 0) {
    mHintUntilMs = 0;
    mRedraw = true;
  }

  if (!mRedraw) return;
  mRedraw = false;
  renderScreen();
  display.display();
}
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
void loop() {
  uint32_t now = millis();

  if (mState == PlayerState::Playing) {
    processAudio();
  }

  handleButtons();
  updateVolume(now);
  updateBattery(now);
  updateShutdown(now);
  updateScroll(now);
  updateDisplay(now);
}

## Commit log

2026-09-27 MP3 Player: SD, I2S Wiedergabe, Taster, Lautstärke, Akku und Boot-Animation
    - Schiebetüren Animation beim Start, Start Text mit Anzahl Titel und Kategorie
    - Ordner auf der SD Karte als Kategorien, Standard Ordner werden angelegt
    - MP3 Wiedergabe über PCM5102 (arduino-audio-tools + libhelix)
    - Taster 1: Play / nächster Titel, Taster 2: Stop / nächste Kategorie
    - Lautstärke per Potentiometer mit Balken in Pixelzeile 31/32
    - Akku Messung alle 30s und bei Titelwechsel, Abschaltung mit Countdown bei 1%
    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
2026-10-02 Platine: KiCad-Projekt mit beidseitig bestückten Modulen
    - Schaltplan und geroutete 2-Lagen-Platine (88 x 52 mm) in hardware/
    - Oberseite: ESP32-C3 SuperMini (gesteckt), OLED, Taster, Poti, Ein/Aus
    - Unterseite: SD-Modul, PCM5102, HW-104 (PAM8403), TP4056
    - Akku-Pfad mit Lademodul, Schalter, Schottky-Diode und Spannungsteiler
    - 470uF/100nF am Verstärker, GND-Flächen auf beiden Lagen
    - Eigene Symbol- und Footprint-Bibliothek, Modulmaße teils geschätzt
    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
    [Esp32C3Mp3Player.kicad_pcb, Esp32C3Mp3Player.kicad_sch]
